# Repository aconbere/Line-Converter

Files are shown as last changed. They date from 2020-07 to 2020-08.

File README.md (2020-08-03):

# Line-Converter

A simple audio line output converter for JAMMA boards. Takes the amplified audio from a JAMMA board and brings them down to consumer audio levels for headphones or your own amplifier. Compatible with either mono or stereo board designs (switchable). Inputs on a block terminal for ease of use, outputs run to a 3.5mm jack.

## Voltage Divider

JAMMA boards will typically output audio at roughly +/- 6V peak to peak, the goal of this board is to reduce that to 0.5V peak to peak expected for standard audio equipment. This board uses a voltage divider bridge with Z1 = 390 Ohms and Z2 = 47 ohms for a ratio of 0.1.

## Isolation

The board also isolates the board from the downstream audio equipment by way of two 1-1 transformers. These are in place to prevent failures in the board cascading to downstream equipement.

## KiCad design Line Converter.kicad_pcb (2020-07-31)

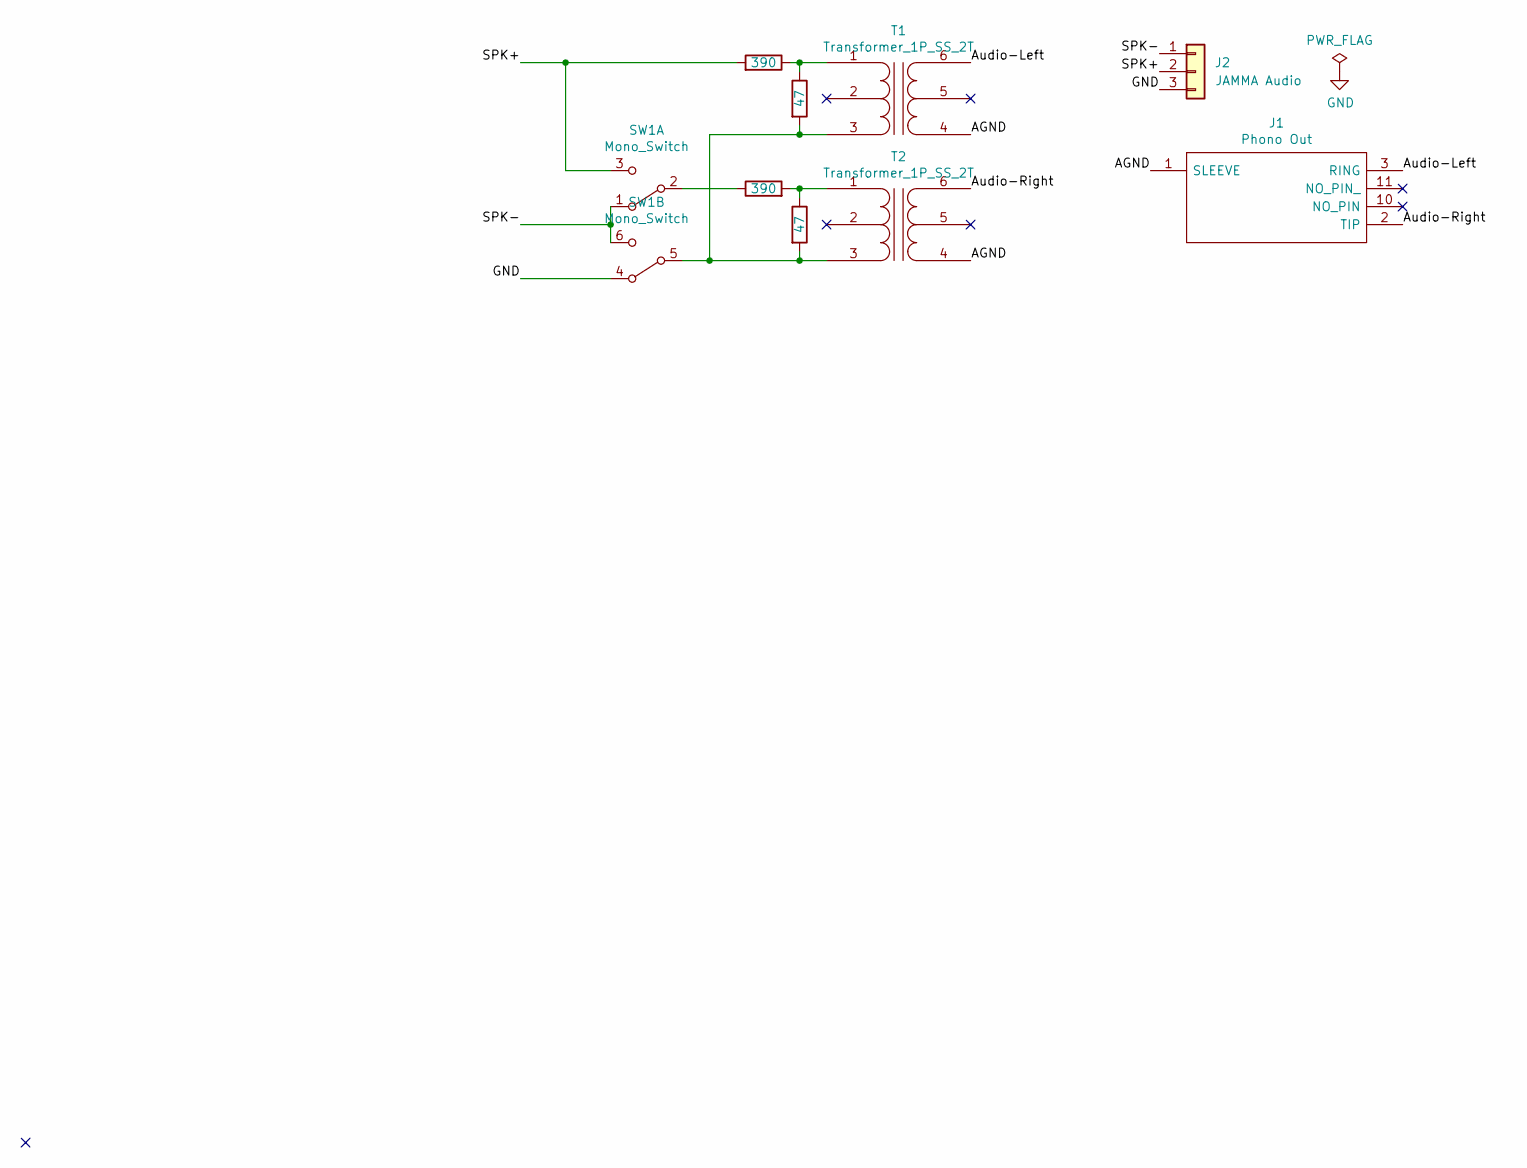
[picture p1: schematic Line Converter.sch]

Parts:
J1: Phono Out; SJ13523N; Mouser Part Number 490-SJ1-3523N
J2: JAMMA Audio; SHDR3W100P0X500_1X3_1500X900X1290P
R10, R11: 390; R_Axial_DIN0204_L3.6mm_D1.6mm_P5.08mm_Horizontal
R12, R13: 47; R_Axial_DIN0204_L3.6mm_D1.6mm_P5.08mm_Horizontal
SW1: Mono_Switch; 400UDP1R1BLKM2RE
T1, T2: Transformer_1P_SS_2T; TY145P

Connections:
/AGND: J1.1 (SLEEVE), T1.4 (SA), T2.4 (SA)
/Audio-Left: J1.3 (RING), T1.6 (SB)
/Audio-Right: J1.2 (TIP), T2.6 (SB)
/SPK+: J2.2, R10.2, SW1.3 (C)
/SPK-: J2.1, SW1.1 (A), SW1.6 (C)
GND: J2.3, SW1.4 (A)
unnamed: R10.1, R12.1, T1.1 (AA)
unnamed: R11.1, SW1.2 (B)
unnamed: R11.2, R13.1, T2.1 (AA)
unnamed: R12.2, R13.2, SW1.5 (B), T1.3 (AB), T2.3 (AB)

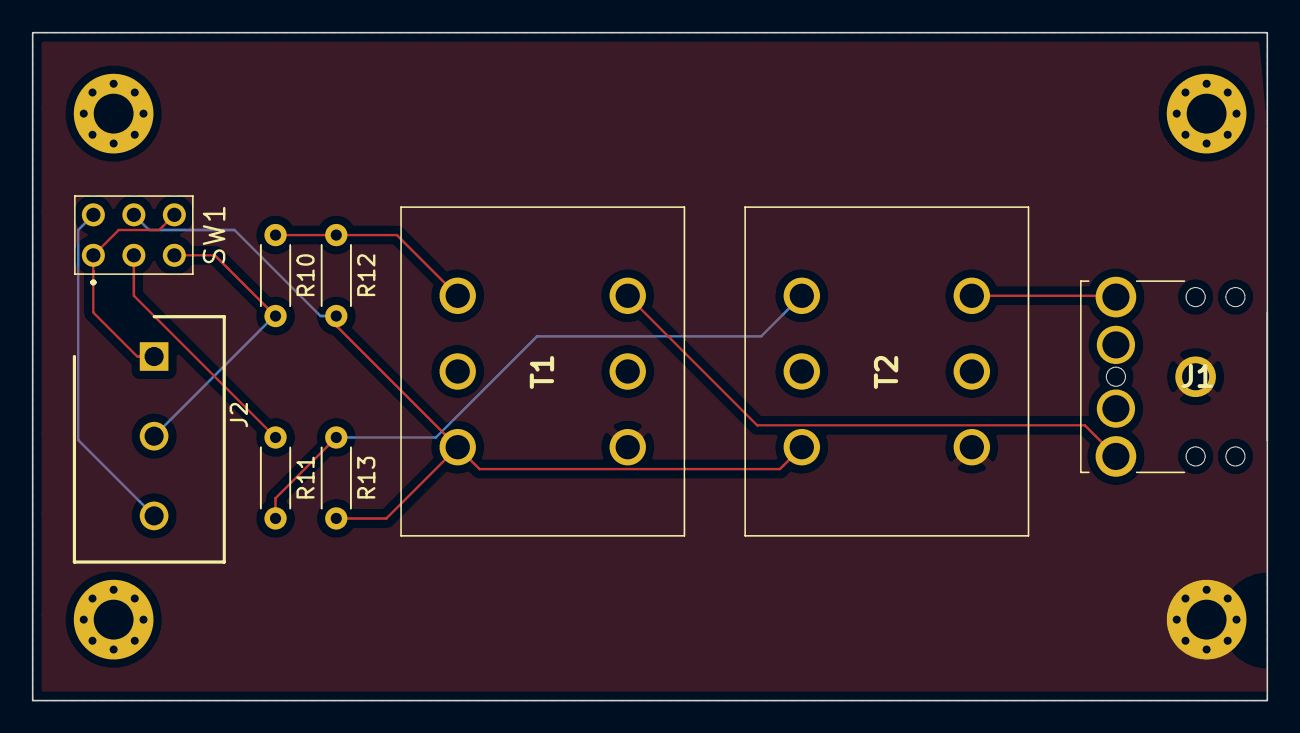
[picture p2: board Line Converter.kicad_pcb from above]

Board: 2 copper layers, 77.5 x 41.9 mm, 9 parts (0 on the bottom side), 10 nets.
